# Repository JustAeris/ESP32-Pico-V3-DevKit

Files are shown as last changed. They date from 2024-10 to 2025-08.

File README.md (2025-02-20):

# ESP32 Pico V3 DevKit 🚀

## Overview 📖
This project features a custom PCB designed for the ESP32 Pico V3, including numerous features and allowing for easy developement. 

## Features ✨
- ✅ **USB-programmable ESP32 Pico V3**
- ✅ **Integrated wireless connectivity**
- ✅ **Full access to all pins and a RGB LED**

## Components 🔧
Here’s a list of the major components used:
- 🔌 **ESP32 Pico V3**
- 🔋 **ANT3216LL00R2400A** Chip antenna
- ⚡ **CP2102N** USB to UART IC

## Hardware 🛠️
The hardware includes:
- 📜 [Schematic diagram link](/hardware/ESP32-PICO-V3-DevKit-Schematic.pdf)
- 🖥️ [PCB design link](https://kicanvas.org/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)

## Software 💻
The ESP32 Pico V3 can be programmed either in C or C++ using the Arduino or ESP-IDF framework. It only supports programming via USB as no ESP-PROG nor JTAG interface has been integrated.

## How to Use 🔍
After assembly, it's simply plug and play! (Although you might need the [CP2102N drivers](https://www.silabs.com/developers/usb-to-uart-bridge-vcp-drivers?tab=downloads) if you want to change the USB-UART chip settings.)

## Board Pictures 📸
Here are some pictures of the bare board:
Bare board
And some pictures of the assembled board:
Full view
<details>
   <summary>See more!</summary>
   <br/>
   
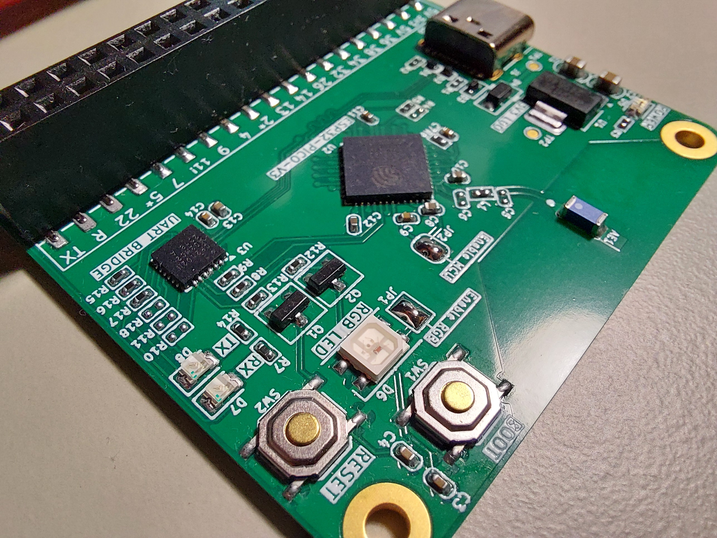
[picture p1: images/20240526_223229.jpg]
Close-up no.1
   
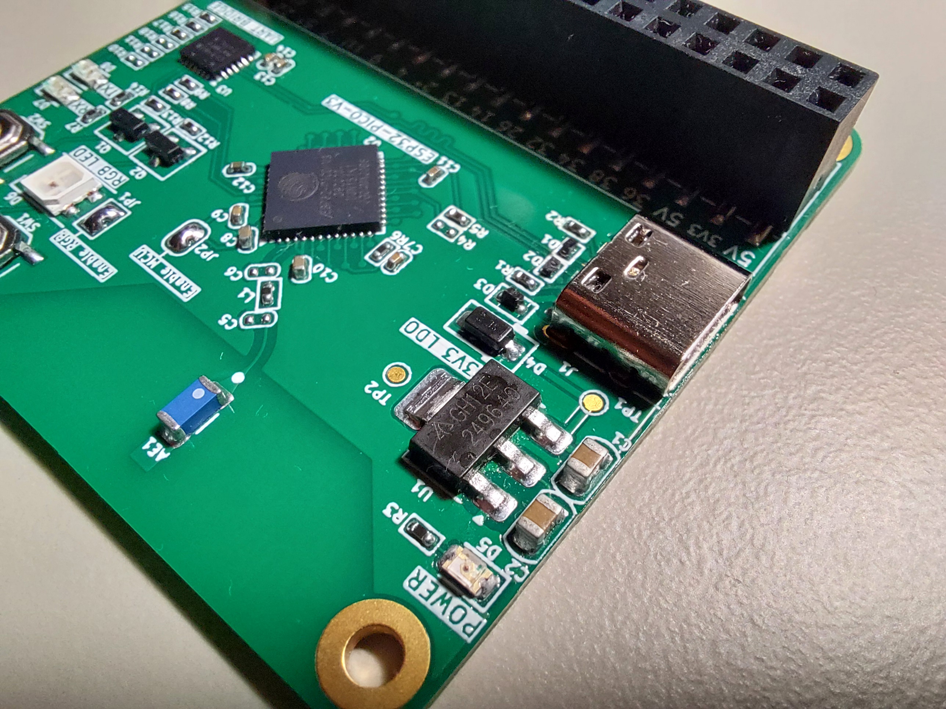
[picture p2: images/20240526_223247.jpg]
Close-up no.2
   
</details>
Feel free to explore the design details and assembly process.

## Known Issues 🐞
There are no known issues for now.
If you encounter any issues, feel free to report them by opening a new issue in the repository.

## License ⚖️
This project is licensed under the GPL-3.0 license - see the LICENSE file for details.

## Contributions 🤝
Feel free to submit issues or pull requests if you find bugs or have suggestions for improvements.

## Contact 📧
For any inquiries, you can reach out to me at [aeris.github@gmail.com](mailto:aeris.github@gmail.com).

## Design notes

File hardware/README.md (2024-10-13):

# Hardware Overview 🛠️

This folder contains the hardware files for the **ESP32Pico V3 DevKit**. Here you'll find all the necessary designs and documents related to the hardware components of the project.

## Contents 📁
- **PCB Designs**: Schematics and layout files created using KiCad.
- **3D Models**: Any 3D models of the components or the assembled board.
- **Bill of Materials (BOM)**: A list of all components used in the project.

## Files Description 📄
- **[ESP32-PICO-V3-DevKit.kicad_pcb]**: The main PCB layout file.
- **[ESP32-PICO-V3-DevKit.kicad_sch]**: The schematic diagram for the circuit.
- **[ESP32-PICO-V3-DevKit-BOM.csv]**: Bill of materials listing all components.
PDF files for the schematic and gerber layers are also included.

## Getting Started ⚙️
1. Open the PCB design in KiCad to view or modify the layout.
2. Use the schematic to understand the circuit connections.
3. Refer to the BOM for component sourcing.

## License ⚖️
This hardware design is licensed under the **GPL-3.0 license**. See the [LICENSE](../LICENSE) file for details.

## Contributing 🤝
If you have suggestions or improvements for the hardware design, feel free to create a pull request or open an issue.

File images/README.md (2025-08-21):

# Images Overview 🖼️

This folder contains images related to the **ESP32 Pico V3 DevKit**. Here you'll find:

- **Board Pictures** 📸: Photos of the assembled hardware.
- **3D Renders** 🏗️: Visualizations of the hardware design.
- **Diagrams and Illustrations** 📝: Any additional visual aids for understanding the project.

Feel free to use these images for reference or documentation purposes! 📂

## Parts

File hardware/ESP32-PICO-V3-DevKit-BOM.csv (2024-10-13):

Reference | Value | Datasheet | Footprint | Qty | DNP
AE1 | ANT3216LL00R2400A | ~ | Personal-Library:ANT3216LL00R2400A | 1
C1,C2 | 22uF | ~ | Capacitor_SMD_Handsoldering_AKL:C_0805_2012Metric | 2
C3,C4,C7,C9,C14 | 0.1uF | ~ | Capacitor_SMD_US_Handsoldering_AKL:C_0402_1005Metric | 5
C5,C6 | TBD | ~ | Capacitor_SMD_US_Handsoldering_AKL:C_0402_1005Metric | 2 | DNP
C8,C10 | 10uF | ~ | Capacitor_SMD_US_Handsoldering_AKL:C_0402_1005Metric | 2
C11,C12 | 1uF | ~ | Capacitor_SMD_US_Handsoldering_AKL:C_0402_1005Metric | 2
C13 | 4.7uF | ~ | Capacitor_SMD_US_Handsoldering_AKL:C_0402_1005Metric | 1
D1,D2 | LESD8D3.3CAT5G | ~ | Diode_SMD_Handsoldering_AKL:D_SOD-882_DFN1006-2_TVS | 2
D3 | LESD5D5.0CT1G | ~ | Diode_SMD_AKL:D_SOD-523_TVS | 1
D4 | 1N5819 | https://www.tme.eu/Document/1dcb17797cd83f32e896ece3030f14cc/1n5817-19.pdf | Diode_SMD_Handsoldering_AKL:D_SOD-123 | 1
D5 | RED | ~ | LED_SMD:LED_0805_2012Metric | 1
D6 | WS2812E-MINI-X1 | https://cdn-shop.adafruit.com/product-files/2686/SK6812MINI_REV.01-1-2.pdf | LED_SMD:LED_SK6812MINI_PLCC4_3.5x3.5mm_P1.75mm | 1
D7,D8 | GREEN | ~ | LED_SMD:LED_0805_2012Metric | 2
J1 | TYPE-C-31-M-12 | https://www.usb.org/sites/default/files/documents/usb_type-c.zip | Connector_USB:USB_C_Receptacle_HRO_TYPE-C-31-M-12 | 1
J2 | Conn_02x19_Top_Bottom | ~ | Connector_PinSocket_2.54mm:PinSocket_2x19_P2.54mm_Vertical_SMD | 1
L1 | TBD | ~ | Inductor_SMD_Handsoldering_AKL:L_0402_1005Metric | 1
Q1,Q2 | S8050 | https://www.tme.eu/Document/724c1368d1e41c0842e24711fa206132/MMSS8050.pdf | Package_TO_SOT_SMD_AKL:SOT-23 | 2
R1,R2 | 5K1 | ~ | Resistor_SMD_AKL:R_0402_1005Metric | 2
R3,R7,R14 | 3K3 | ~ | Resistor_SMD_AKL:R_0402_1005Metric | 3
R4,R18 | 10K | ~ | Resistor_SMD_AKL:R_0402_1005Metric | 2 | DNP
R5,R6,R12,R13 | 10K | ~ | Resistor_SMD_AKL:R_0402_1005Metric | 4
R8,R9 | 1K | ~ | Resistor_SMD_AKL:R_0402_1005Metric | 2
R10,R11 | 0 | ~ | Resistor_SMD_AKL:R_0402_1005Metric | 2 | DNP
R15 | 47K5 | ~ | Resistor_SMD_AKL:R_0402_1005Metric | 1
R16 | 22K1 | ~ | Resistor_SMD_AKL:R_0402_1005Metric | 1
R17 | 2K | ~ | Resistor_SMD_AKL:R_0402_1005Metric | 1
SW1 | BOOT BUTTON | ~ | Button_Switch_SMD:SW_Push_1P1T_XKB_TS-1187A | 1
SW2 | RESET BUTTON | ~ | Button_Switch_SMD:SW_Push_1P1T_XKB_TS-1187A | 1
TP1 | V_{BUS} | ~ | TestPoint:TestPoint_Pad_D1.0mm | 1
TP2 | 3V3 | ~ | TestPoint:TestPoint_Pad_D1.0mm | 1
U1 | AP2114H-3.3TRG1 | https://www.lcsc.com/datasheet/lcsc_datasheet_2304140030_Diodes-Incorporated-AP2114H-3-3TRG1_C150716.pdf | Package_TO_SOT_SMD:SOT-223-3_TabPin2 | 1
U2 | ESP32-PICO-V3 | https://www.espressif.com/sites/default/files/documentation/esp32-pico-v3_datasheet_en.pdf | Package_DFN_QFN:QFN-48-1EP_7x7mm_P0.5mm_EP5.1x5.1mm | 1
U3 | CP2102N-Axx-xQFN24 | https://www.silabs.com/documents/public/data-sheets/cp2102n-datasheet.pdf | Package_DFN_QFN:QFN-24-1EP_4x4mm_P0.5mm_EP2.6x2.6mm | 1

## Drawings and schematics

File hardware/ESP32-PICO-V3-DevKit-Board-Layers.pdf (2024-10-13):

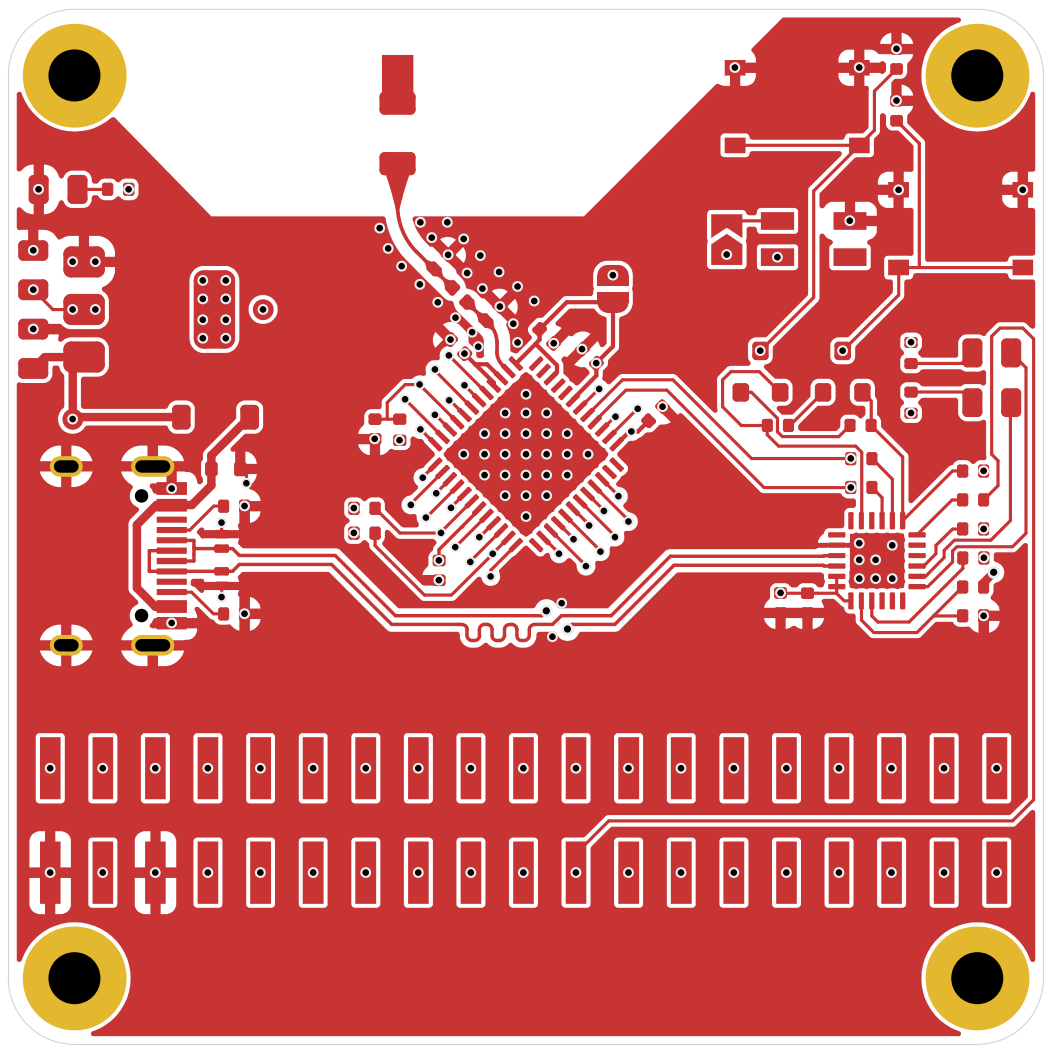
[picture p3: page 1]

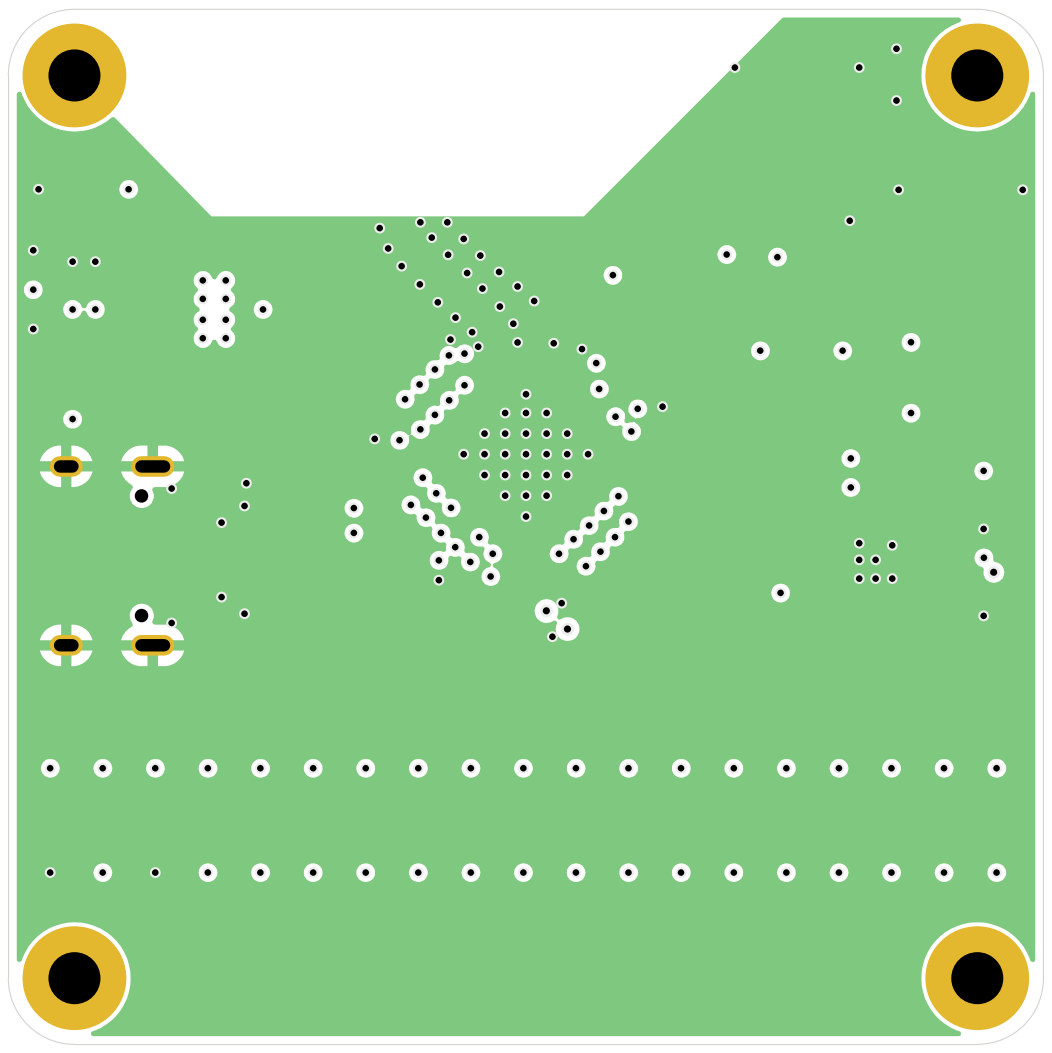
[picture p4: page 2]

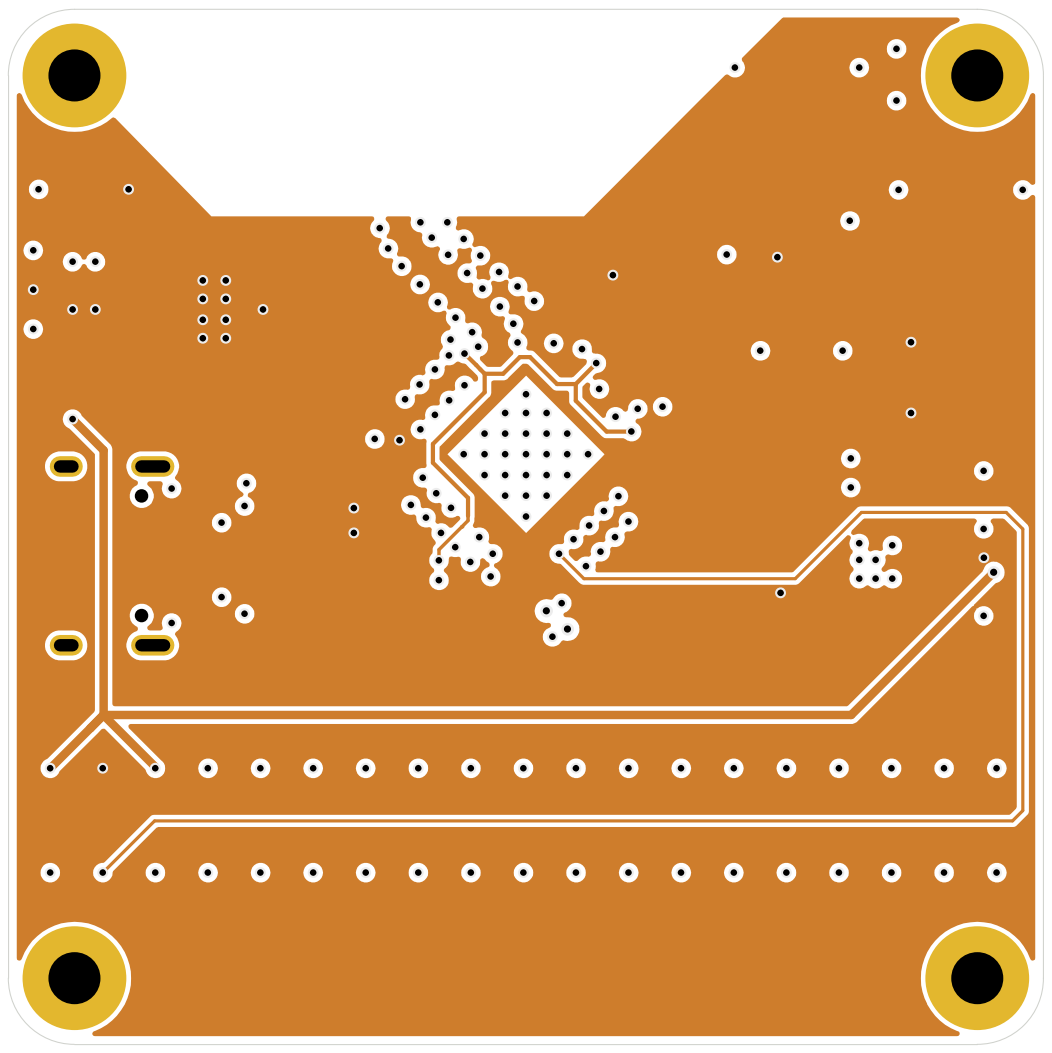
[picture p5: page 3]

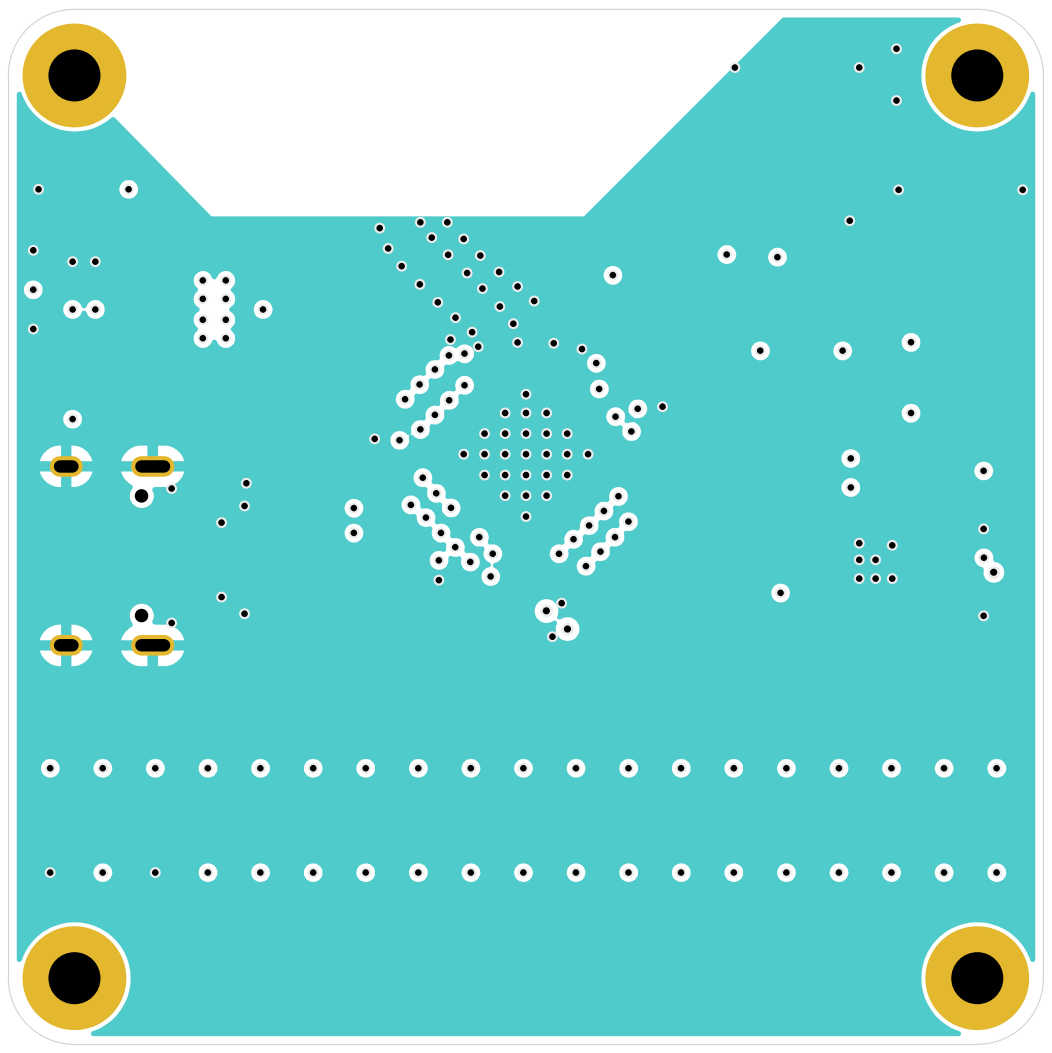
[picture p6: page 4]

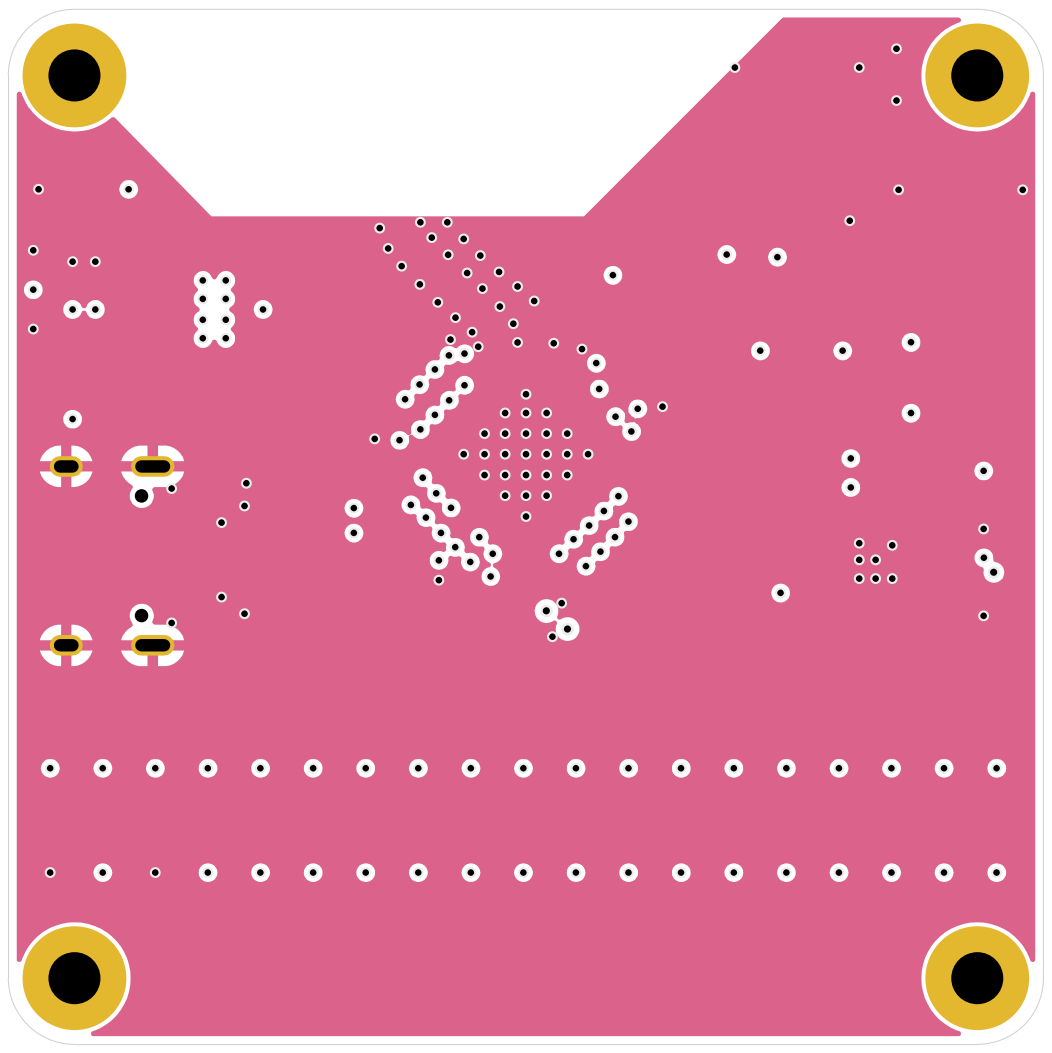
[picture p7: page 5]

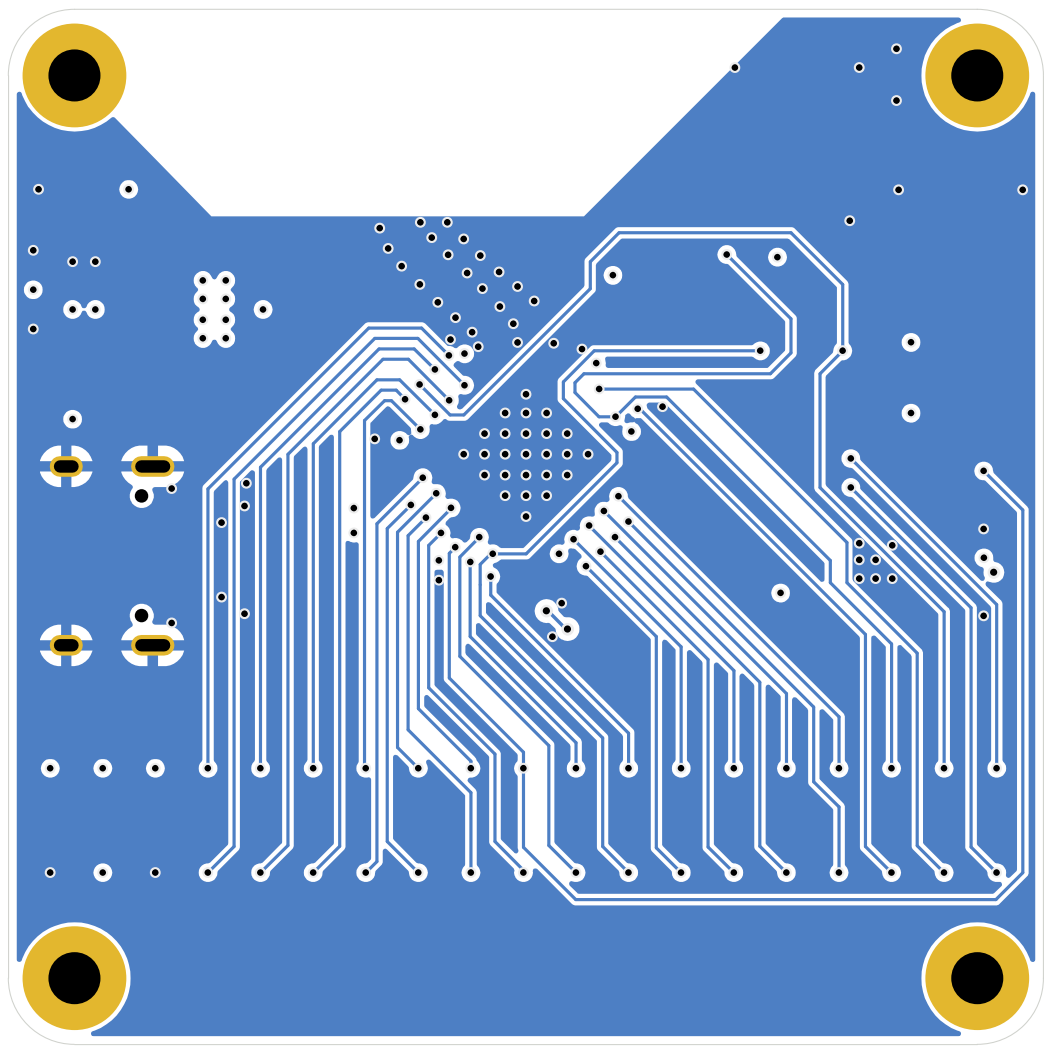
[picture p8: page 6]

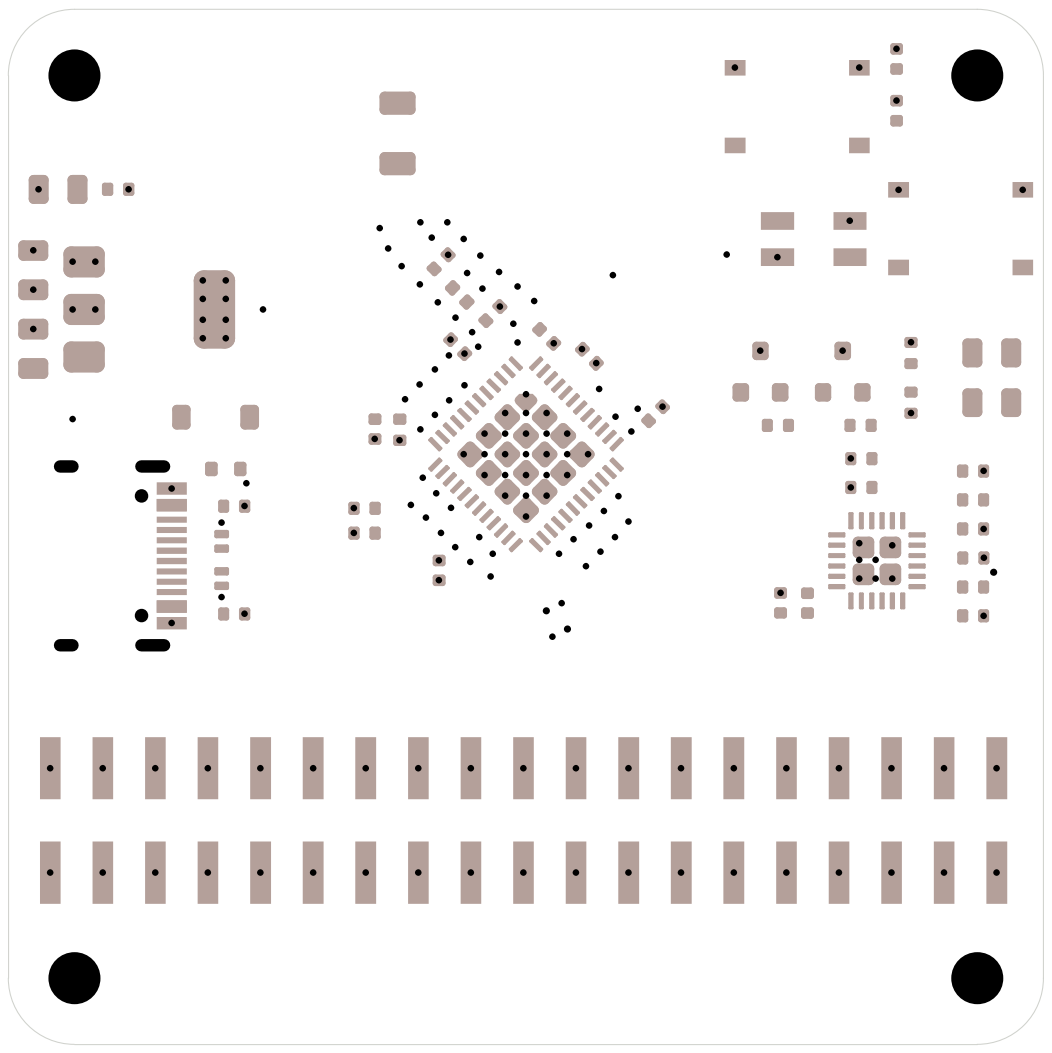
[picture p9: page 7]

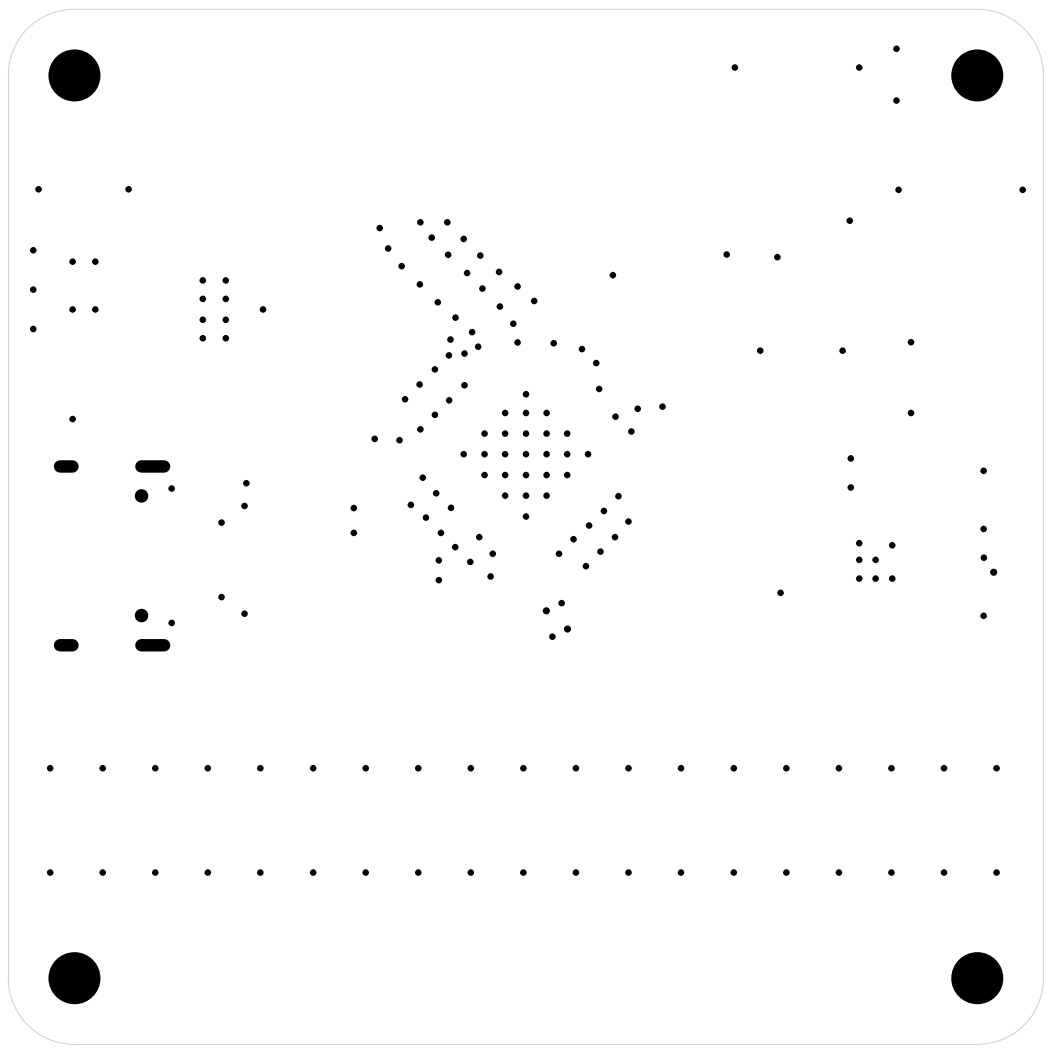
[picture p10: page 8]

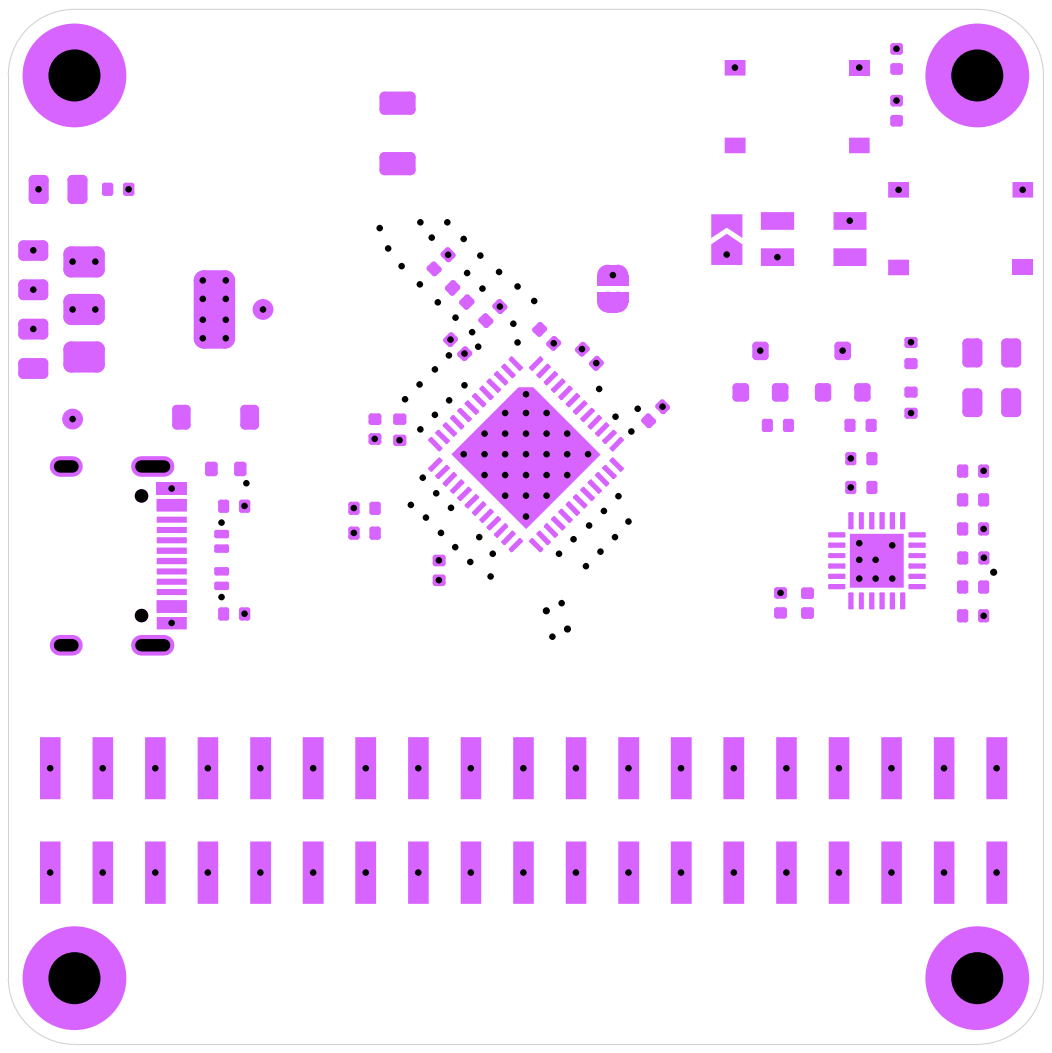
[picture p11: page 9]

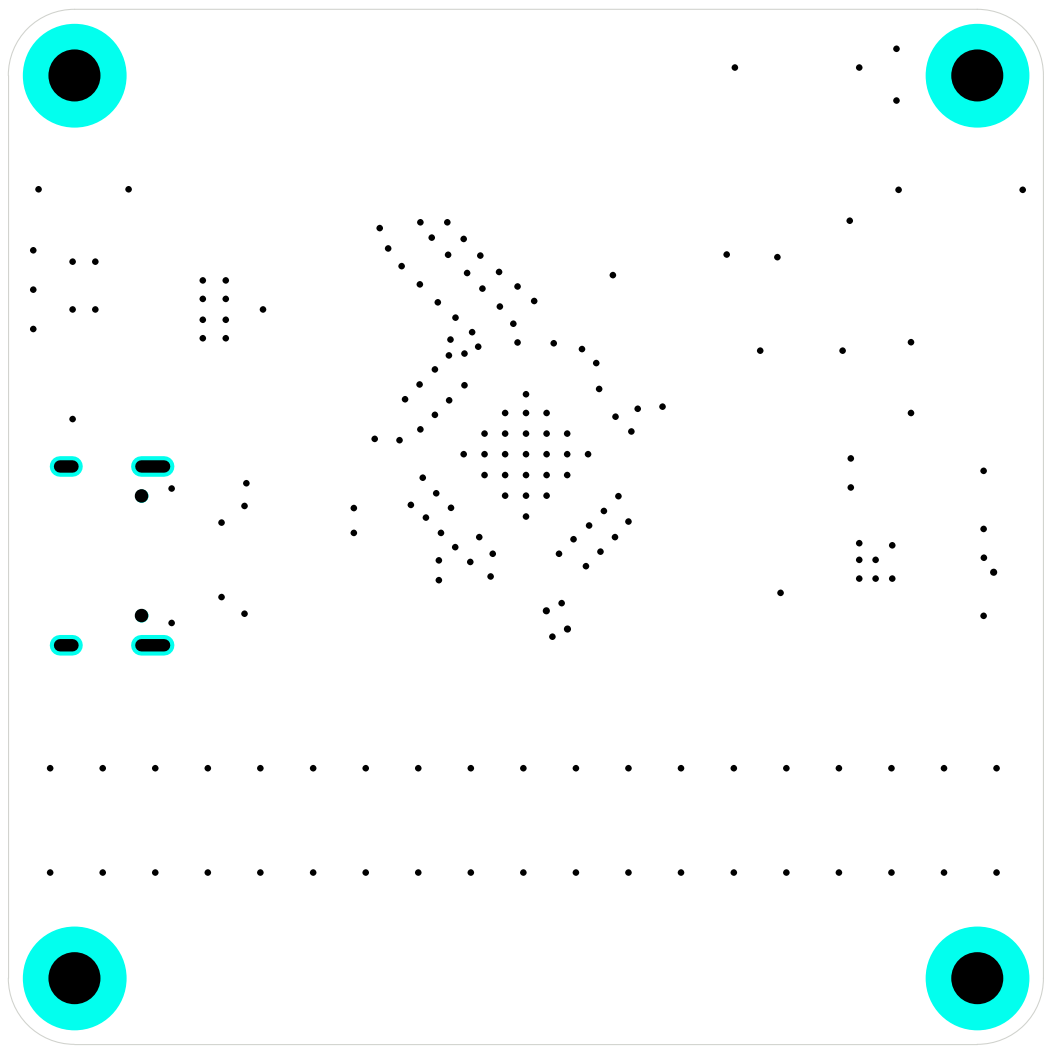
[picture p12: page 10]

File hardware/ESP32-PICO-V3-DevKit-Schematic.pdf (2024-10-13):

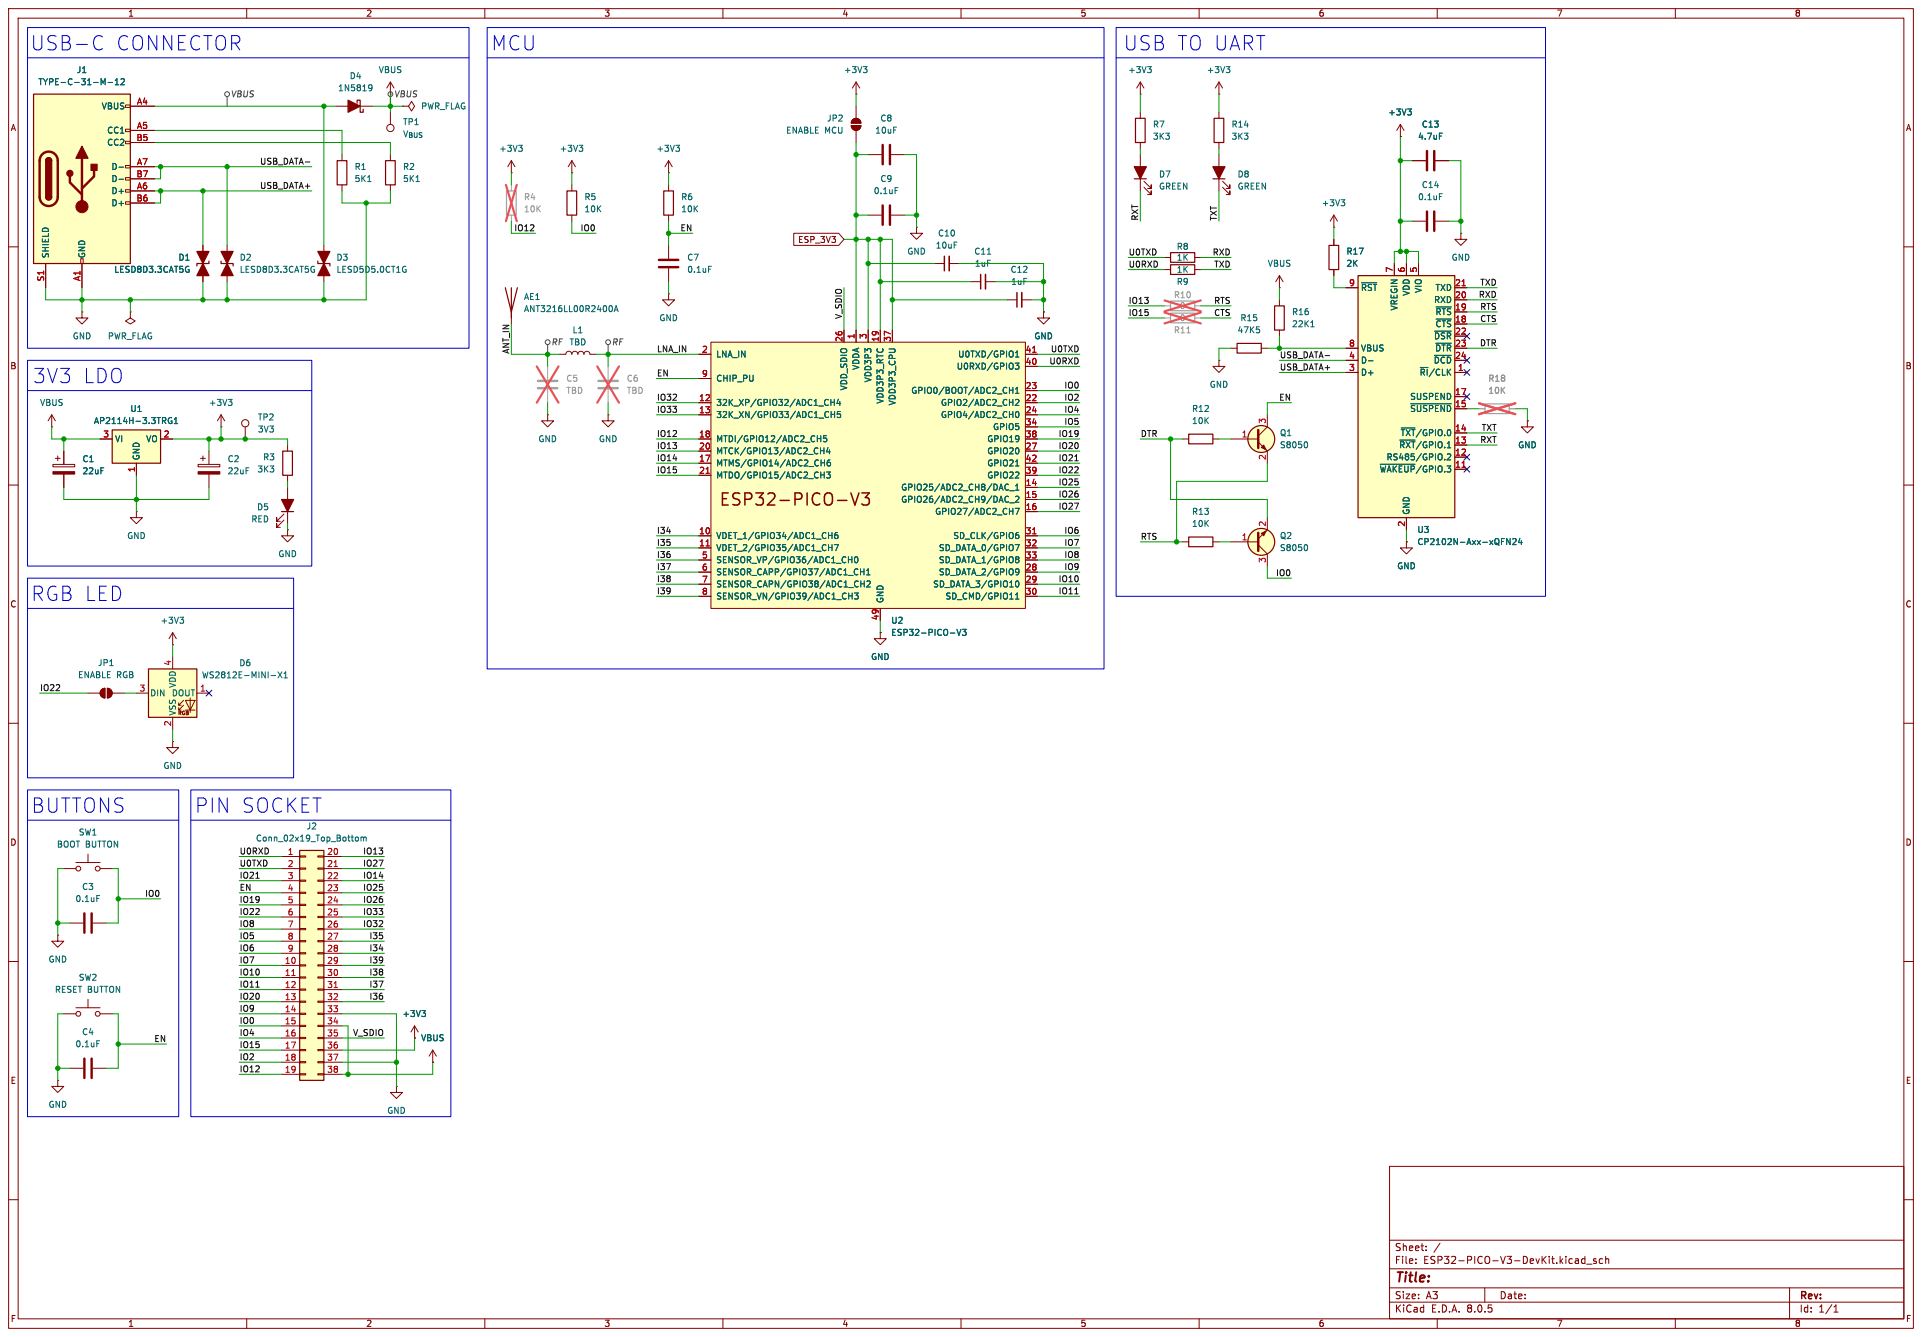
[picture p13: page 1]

2 RXD 20 TXD 21 ~{DSR} 22 ~{DTR} 23 ~{DCD} 24 D+ 3 D- 4 VIO

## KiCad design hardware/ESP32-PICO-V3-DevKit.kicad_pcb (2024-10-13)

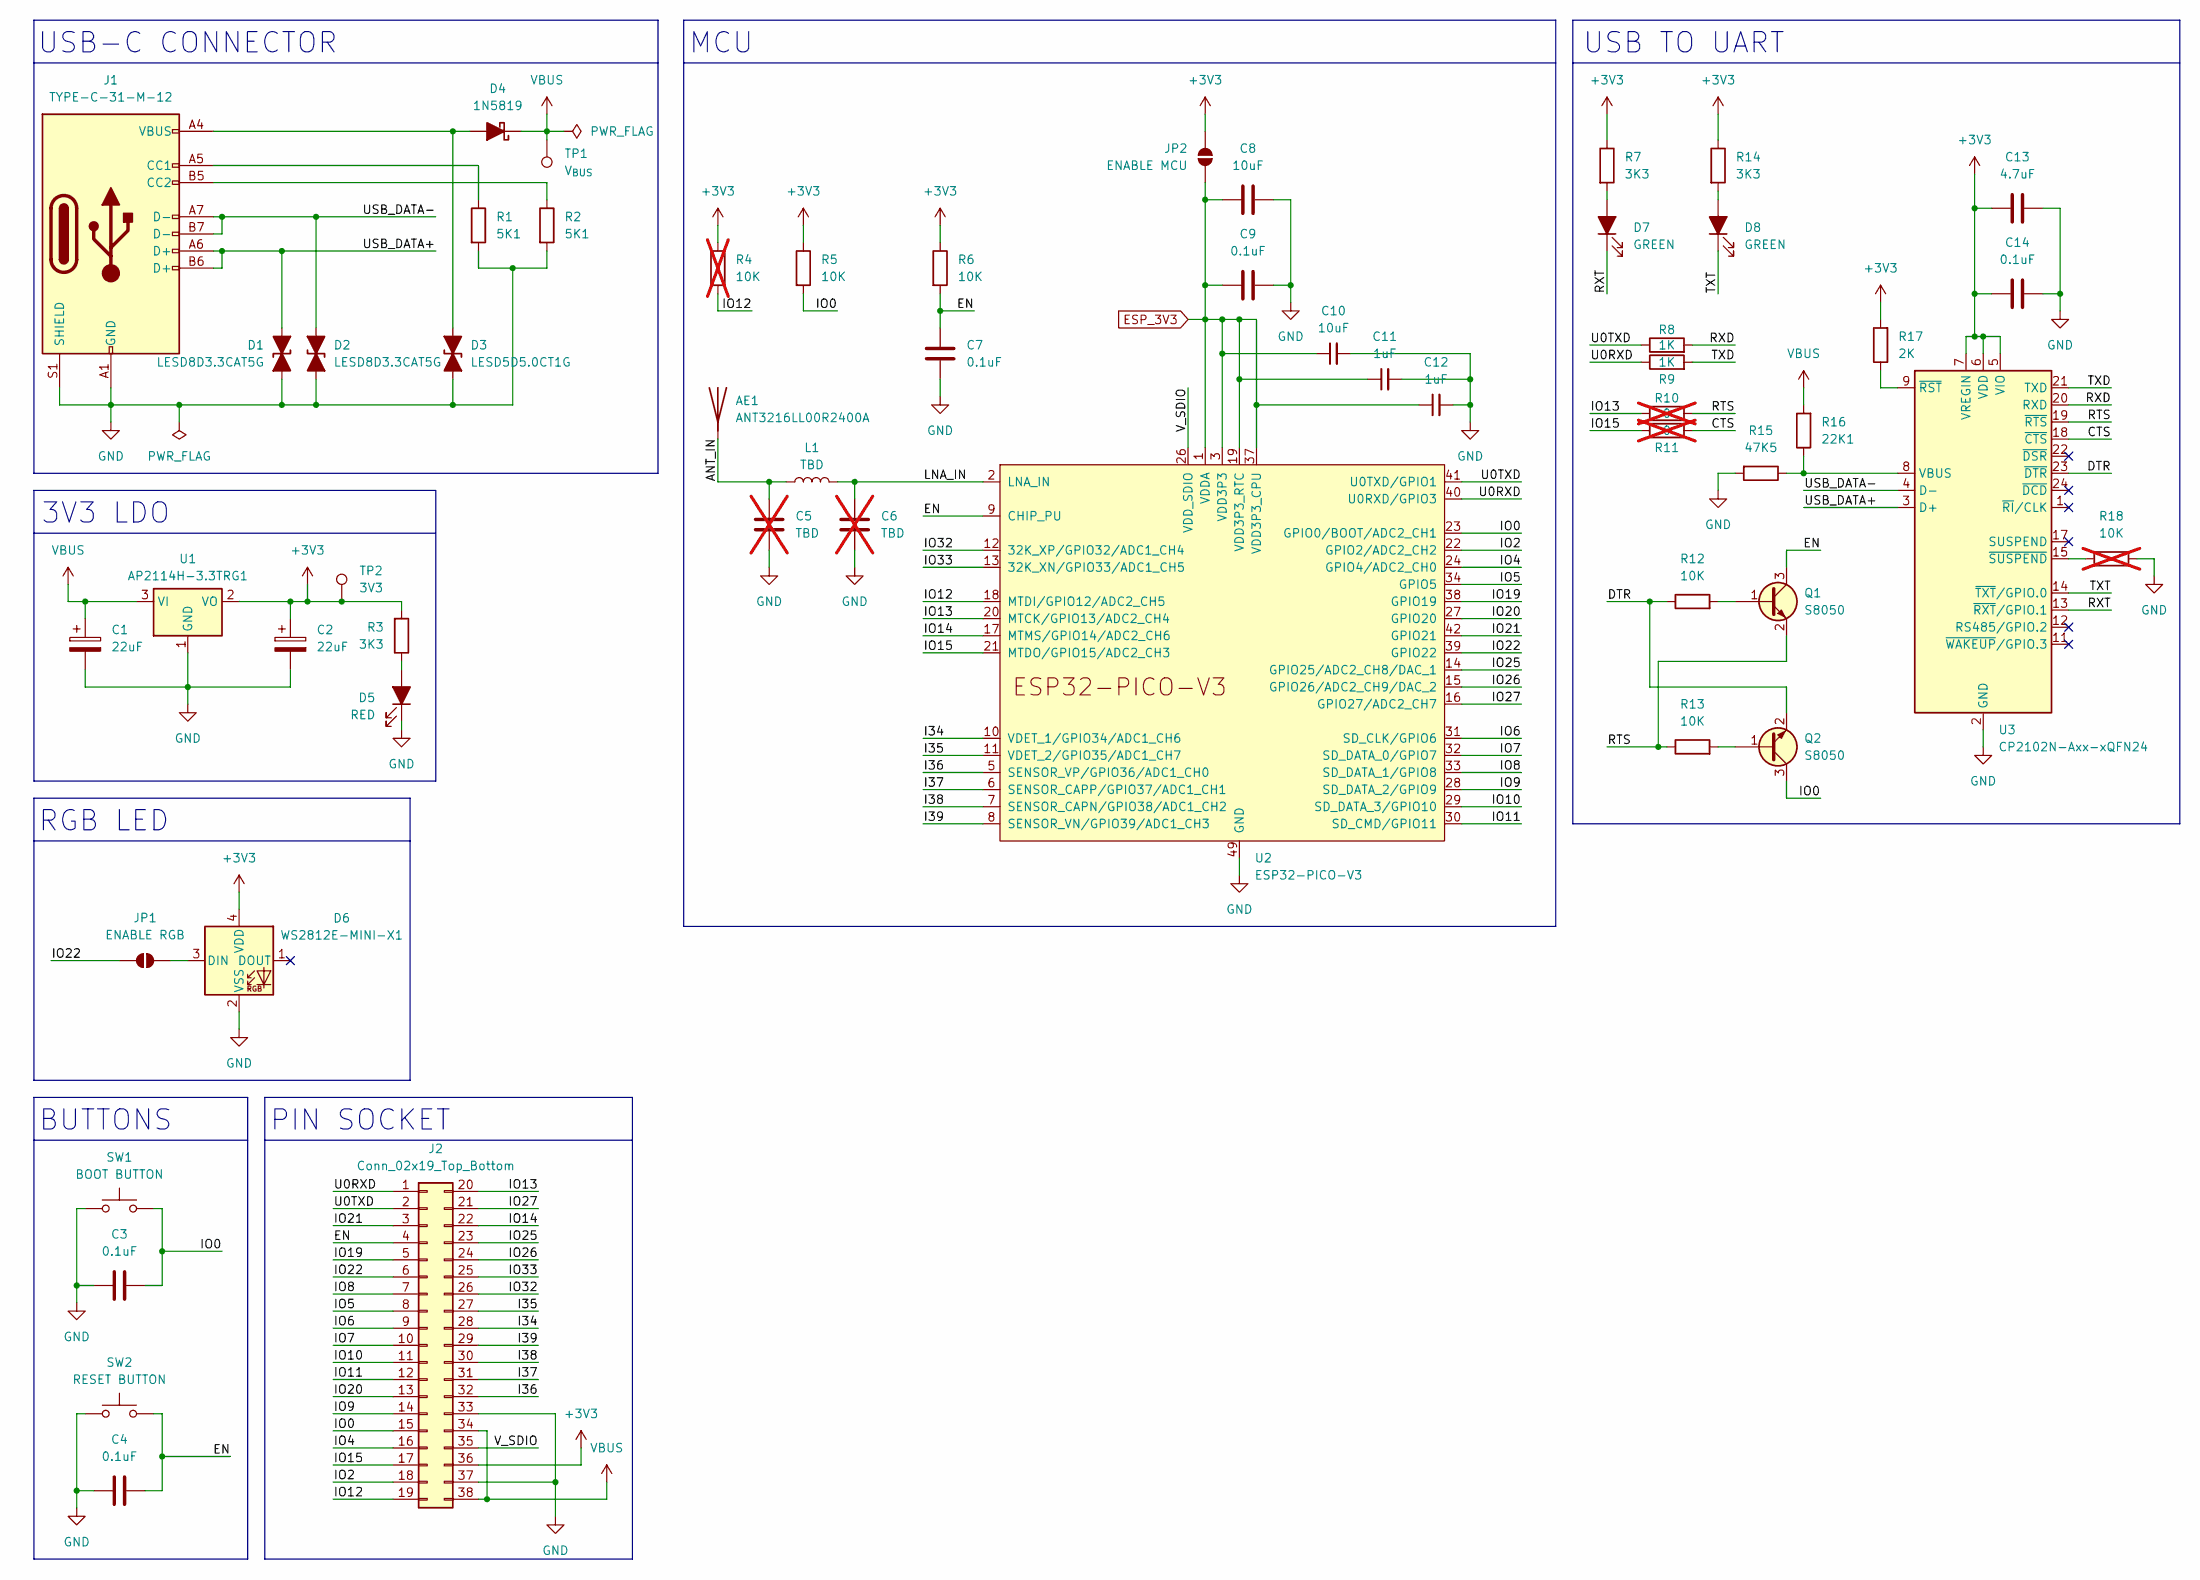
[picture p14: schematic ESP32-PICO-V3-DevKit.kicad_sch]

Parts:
AE1: ANT3216LL00R2400A
C1, C2: 22uF; C_0805_2012Metric
C3, C4, C7, C9, C14: 0.1uF; C_0402_1005Metric
C5, C6: TBD; C_0402_1005Metric; not fitted
C8, C10: 10uF; C_0402_1005Metric
C11, C12: 1uF; C_0402_1005Metric
C13: 4.7uF; C_0402_1005Metric
D1, D2: LESD8D3.3CAT5G; D_SOD-882_DFN1006-2_TVS
D3: LESD5D5.0CT1G; D_SOD-523_TVS
D4: 1N5819; D_SOD-123
D5: RED; LED_0805_2012Metric
D6: WS2812E-MINI-X1; LED_SK6812MINI_PLCC4_3.5x3.5mm_P1.75mm
D7, D8: GREEN; LED_0805_2012Metric
J1: TYPE-C-31-M-12; USB_C_Receptacle_HRO_TYPE-C-31-M-12
J2: Conn_02x19_Top_Bottom; PinSocket_2x19_P2.54mm_Vertical_SMD
JP1: ENABLE RGB; SolderJumper-2_P1.3mm_Open_TrianglePad1.0x1.5mm
JP2: ENABLE MCU; SolderJumper-2_P1.3mm_Open_RoundedPad1.0x1.5mm
L1: TBD; L_0402_1005Metric
Q1, Q2: S8050; SOT-23
R1, R2: 5K1; R_0402_1005Metric
R3, R7, R14: 3K3; R_0402_1005Metric
R4, R18: 10K; R_0402_1005Metric; not fitted
R5, R6, R12, R13: 10K; R_0402_1005Metric
R8, R9: 1K; R_0402_1005Metric
R10, R11: 0; R_0402_1005Metric; not fitted
R15: 47K5; R_0402_1005Metric
R16: 22K1; R_0402_1005Metric
R17: 2K; R_0402_1005Metric
SW1: BOOT BUTTON; SW_Push_1P1T_XKB_TS-1187A
SW2: RESET BUTTON; SW_Push_1P1T_XKB_TS-1187A
TP1: V_{BUS}; TestPoint_Pad_D1.0mm
TP2: 3V3; TestPoint_Pad_D1.0mm
U1: AP2114H-3.3TRG1; SOT-223-3_TabPin2
U2: ESP32-PICO-V3; QFN-48-1EP_7x7mm_P0.5mm_EP5.1x5.1mm
U3: CP2102N-Axx-xQFN24; QFN-24-1EP_4x4mm_P0.5mm_EP2.6x2.6mm

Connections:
+3V3: C2.1, C13.2, C14.2, D6.4 (VDD), J2.36, JP2.2 (B), R3.2, R4.1, R5.1, R6.1, R7.1, R14.1, R17.2, TP2.1, U1.2 (VO), U3.5 (VIO), U3.6 (VDD), U3.7 (VREGIN)
/ANT_IN: AE1.1 (A), C5.1, L1.1
/CTS: R11.2, U3.18 (~CTS)
/DTR: Q2.2 (E), R12.1, U3.23 (~DTR)
/EN: C4.2, C7.1, J2.4, Q1.3 (C), R6.2, SW2.2, U2.9 (CHIP_PU)
/I34: J2.28, U2.10 (VDET_1/GPIO34/ADC1_CH6)
/I35: J2.27, U2.11 (VDET_2/GPIO35/ADC1_CH7)
/I36: J2.32, U2.5 (SENSOR_VP/GPIO36/ADC1_CH0)
/I37: J2.31, U2.6 (SENSOR_CAPP/GPIO37/ADC1_CH1)
/I38: J2.30, U2.7 (SENSOR_CAPN/GPIO38/ADC1_CH2)
/I39: J2.29, U2.8 (SENSOR_VN/GPIO39/ADC1_CH3)
/IO0: C3.2, J2.15, Q2.3 (C), R5.2, SW1.2, U2.23 (GPIO0/BOOT/ADC2_CH1)
/IO2: J2.18, U2.22 (GPIO2/ADC2_CH2)
/IO4: J2.16, U2.24 (GPIO4/ADC2_CH0)
/IO5: J2.8, U2.34 (GPIO5)
/IO6: J2.9, U2.31 (SD_CLK/GPIO6)
/IO7: J2.10, U2.32 (SD_DATA_0/GPIO7)
/IO8: J2.7, U2.33 (SD_DATA_1/GPIO8)
/IO9: J2.14, U2.28 (SD_DATA_2/GPIO9)
/IO10: J2.11, U2.29 (SD_DATA_3/GPIO10)
/IO11: J2.12, U2.30 (SD_CMD/GPIO11)
/IO12: J2.19, R4.2, U2.18 (MTDI/GPIO12/ADC2_CH5)
/IO13: J2.20, R10.1, U2.20 (MTCK/GPIO13/ADC2_CH4)
/IO14: J2.22, U2.17 (MTMS/GPIO14/ADC2_CH6)
/IO15: J2.17, R11.1, U2.21 (MTDO/GPIO15/ADC2_CH3)
/IO19: J2.5, U2.38 (GPIO19)
/IO20: J2.13, U2.27 (GPIO20)
/IO21: J2.3, U2.42 (GPIO21)
/IO22: J2.6, JP1.1 (A), U2.39 (GPIO22)
/IO25: J2.23, U2.14 (GPIO25/ADC2_CH8/DAC_1)
/IO26: J2.24, U2.15 (GPIO26/ADC2_CH9/DAC_2)
/IO27: J2.21, U2.16 (GPIO27/ADC2_CH7)
/IO32: J2.26, U2.12 (32K_XP/GPIO32/ADC1_CH4)
/IO33: J2.25, U2.13 (32K_XN/GPIO33/ADC1_CH5)
/LNA_IN: C6.1, L1.2, U2.2 (LNA_IN)
/RTS: Q1.2 (E), R10.2, R13.1, U3.19 (~RTS)
/RXD: R8.2, U3.20 (RXD)
/RXT: D7.1 (K), U3.13 (~RXT/GPIO.1)
/TXD: R9.2, U3.21 (TXD)
/TXT: D8.1 (K), U3.14 (~TXT/GPIO.0)
/U0RXD: J2.1, R9.1, U2.40 (U0RXD/GPIO3)
/U0TXD: J2.2, R8.1, U2.41 (U0TXD/GPIO1)
/USB_DATA+: D1.2 (A2), J1.A6 (D+), J1.B6 (D+), U3.3 (D+)
/USB_DATA-: D2.2 (A2), J1.A7 (D-), J1.B7 (D-), U3.4 (D-)
/V_SDIO: J2.35, U2.26 (VDD_SDIO)
ESP_3V3: C8.2, C9.2, C10.1, C11.1, C12.1, JP2.1 (A), U2.1 (VDDA), U2.3 (VDD3P3), U2.4 (VDD3P3), U2.19 (VDD3P3_RTC), U2.37 (VDD3P3_CPU), U2.43 (VDDA), U2.46 (VDDA)
GND: C1.2, C2.2, C3.1, C4.1, C5.2, C6.2, C7.2, C8.1, C9.1, C10.2, C11.2, C12.2, C13.1, C14.1, D1.1 (A1), D2.1 (A1), D3.1 (A1), D5.1 (K), D6.2 (VSS), J1.A1 (GND), J1.A12 (GND), J1.B1 (GND), J1.B12 (GND), J1.S1 (SHIELD), J2.33, J2.37, R1.2, R2.2, R15.2, R18.2, SW1.1, SW2.1, U1.1 (GND), U2.49 (GND), U3.2 (GND), U3.25 (GND)
unnamed: D3.2 (A2), D4.2 (A), J1.A4 (VBUS), J1.A9 (VBUS), J1.B4 (VBUS), J1.B9 (VBUS)
unnamed: D5.2 (A), R3.1
unnamed: D6.3 (DIN), JP1.2 (B)
unnamed: D7.2 (A), R7.2
unnamed: D8.2 (A), R14.2
unnamed: J1.A5 (CC1), R1.1
unnamed: J1.B5 (CC2), R2.1
unnamed: Q1.1 (B), R12.2
unnamed: Q2.1 (B), R13.2
unnamed: R15.1, R16.1, U3.8 (VBUS)
unnamed: R17.1, U3.9 (~RST)
unnamed: R18.1, U3.15 (~SUSPEND)
VBUS: C1.1, D4.1 (K), J2.34, J2.38, R16.2, TP1.1, U1.3 (VI)

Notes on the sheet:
RGB LED
USB TO UART
BUTTONS
3V3 LDO
MCU
USB-C CONNECTOR
PIN SOCKET

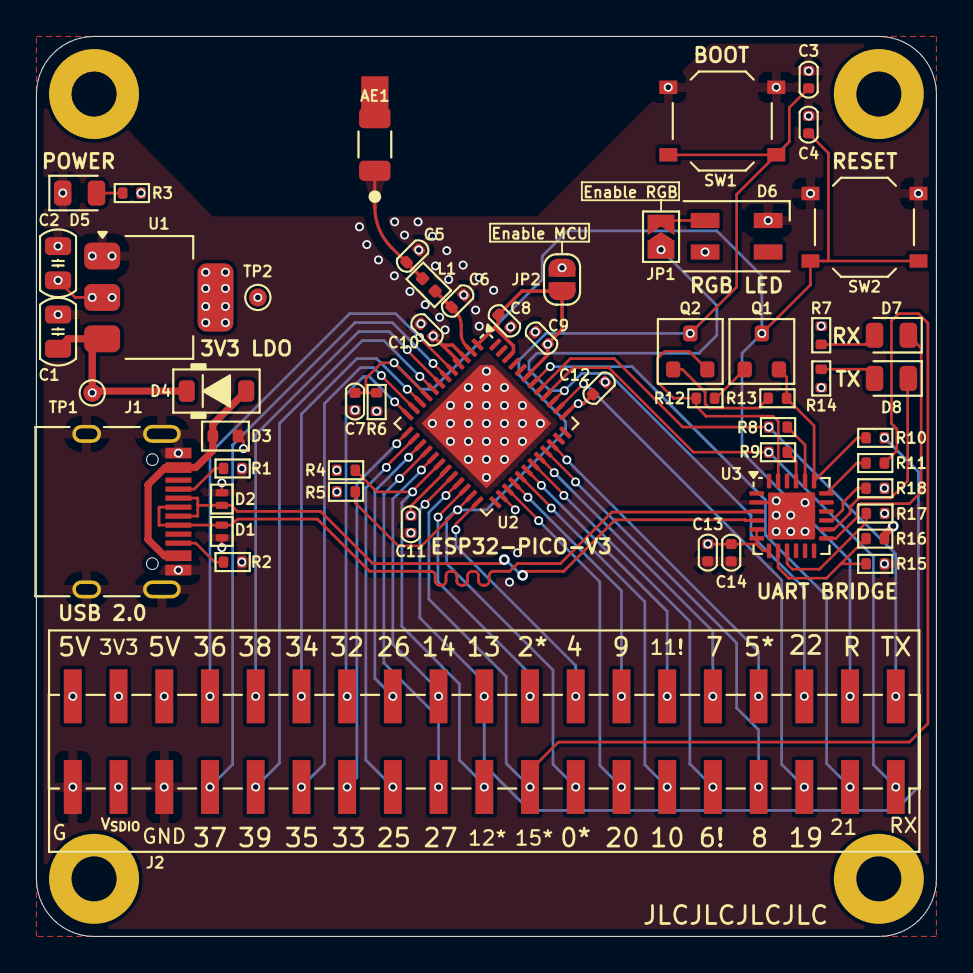
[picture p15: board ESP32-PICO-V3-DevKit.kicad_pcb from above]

Board: 6 copper layers, 50.0 x 50.0 mm, 55 parts (0 on the bottom side), 60 nets.
